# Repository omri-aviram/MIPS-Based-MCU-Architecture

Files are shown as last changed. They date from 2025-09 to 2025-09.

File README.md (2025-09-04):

# MIPS-Based-MCU-Architecture
This project implements a full MCU system on FPGA, based on a  scalar pipelined MIPS processor. The system integrates core  CPU functionality with memory, bus infrastructure, and  memory-mapped peripherals, creating a working  microcontroller-like environment.  The design was written in VHDL

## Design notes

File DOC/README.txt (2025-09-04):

============================================================
README — MCU Project (MIPS-based Microcontroller on FPGA)
============================================================

Authors:
  • Tal Adoni (31987300)
  • Omri Aviram (312192669)

------------------------------------------------------------
1. Project Overview
------------------------------------------------------------
This project implements a full MCU system on FPGA, based on a 
scalar pipelined MIPS processor. The system integrates core 
CPU functionality with memory, bus infrastructure, and 
memory-mapped peripherals, creating a working 
microcontroller-like environment.

The design was written in VHDL, simulated with ModelSim, and 
synthesized for Altera/Intel Cyclone V FPGA (DE10-Standard 
development board). Timing constraints and functional testing 
were applied to ensure correct operation in hardware.

------------------------------------------------------------
2. System Architecture
------------------------------------------------------------
Top-Level: Quartus_Top.vhd
  • Connects CPU, instruction/data memories, and peripherals.
  • Defines generics for bus width, address width, and 
    synthesis/simulation parameters.
  • Instantiates clocking and reset logic.

Main Components:
  • MIPS.vhd — Pipelined MIPS CPU with 5 pipeline stages:
      - IFETCH.vhd
      - IDECODE.vhd
      - EXECUTE.vhd
      - DMEMORY.vhd
      - CONTROL.vhd
      - HazardUnit_and_ForwardingUnit.vhd
  • MCU.vhd — Wraps CPU with peripheral bus and system control.
  • IO_decoder.vhd — Maps I/O addresses to peripherals.
  • Interrupt_controller.vhd — Handles external/internal IRQs.

Memory:
  • ITCM (Instruction Tightly-Coupled Memory)
  • DTCM (Data Tightly-Coupled Memory)
  • Synchronus FIFO.vhd — FIFO buffer used for FIR/IO
  • Counter.vhd — Generic n-bit counter (timing/events)

Peripherals:
  • Basic_Timer.vhd — Generates interrupts and PWM signals.
  • FIR_filter.vhd — Digital FIR accelerator with FIFO 
    interface for streaming data.
  • HexDecoder.vhd — Drives FPGA 7-segment displays.
  • BidirPin.vhd — Bidirectional I/O pin module.

Packages:
  • const_package.vhd — Global constants (word sizes, addresses).
  • aux_package.vhd — Helper functions and types.
  • cond_comilation_package.vhd — Conditional compilation 
    definitions.

------------------------------------------------------------
3. Features
------------------------------------------------------------
  • Scalar pipelined MIPS CPU (5 stages + hazard resolution).
  • Instruction & Data memories with M9K FPGA blocks.
  • Memory-mapped peripherals: Timer, GPIO, FIR, FIFO, etc.
  • Interrupt controller with priority and vectoring support.
  • Bus-based IO decoding for modular expansion.
  • Clock division for peripherals (FIRCLK ~44 kHz).
  • Hex display output for debugging.

------------------------------------------------------------
4. Simulation & Synthesis
------------------------------------------------------------
Simulation:
  • ModelSim testbenches verify pipeline correctness, memory 
    writes, and peripheral functionality.
  • FIFO and FIR modules were tested with waveform inspection.

Synthesis:
  • Quartus Prime with Cyclone V device.
  • Timing analysis performed with .sdc constraints:
      - create_clock for CLK_IN (50 MHz)
      - derive_pll_clocks for generated clocks
      - FIRCLK domain treated as asynchronous (optional)
  • FPGA tested with actual memory write/read and FIR output.

------------------------------------------------------------
5. Known Issues & Debugging Notes
------------------------------------------------------------
  • ModelSim and Quartus may show different memory initialization 
    order (endianness difference in hex files).
  • FIR filter requires consistent FIFO widths (cell_size must 
    match higher-level instantiations).
  • Critical paths in Quartus should be analyzed to maintain Fmax.
  • Ensure FIFOREN/FIFOWEN signals are pulsed properly to avoid 
    latching issues.

------------------------------------------------------------
6. File List
------------------------------------------------------------
  • Quartus_Top.vhd
  • MCU.vhd
  • MIPS.vhd
    ├── IFETCH.vhd
    ├── IDECODE.vhd
    ├── EXECUTE.vhd
    ├── DMEMORY.vhd
    ├── CONTROL.vhd
    └── HazardUnit_and_ForwardingUnit.vhd
  • Synchronus FIFO.vhd
  • Basic_Timer.vhd
  • FIR_filter.vhd
  • Counter.vhd
  • HexDecoder.vhd
  • IO_decoder.vhd
  • Interrupt_controller.vhd
  • BidirPin.vhd
  • const_package.vhd
  • aux_package.vhd
  • cond_comilation_package.vhd

------------------------------------------------------------
7. Usage Instructions
------------------------------------------------------------
1. Open Quartus project and add all VHDL files.
2. Apply SDC constraints for proper timing closure.
3. Compile project for Cyclone V FPGA (DE10-Standard).
4. Program the FPGA with the generated .sof file.
5. Interact with system via memory-mapped IO (keys, switches, 
   UART or testbench).

------------------------------------------------------------
8. License
------------------------------------------------------------
This project was developed as part of an academic course. 
It is intended for educational purposes only.

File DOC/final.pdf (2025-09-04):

# Final Project - REPORT

# ADVANCED CPU ARCHITECTURE AND HARDWARE MIPS Based MCU Architecture

## Tal Adoni – 319087300

## Omri Aviram – 312192669

במעבדה זו הי ה עלינו לממש architecture MCU based MIPS המשתמשת במעבד ה-MIPS שיצרנו במעבדה קודמת ומחברת אותו עם רכיב ים פריפריאליים באו פן הב א:

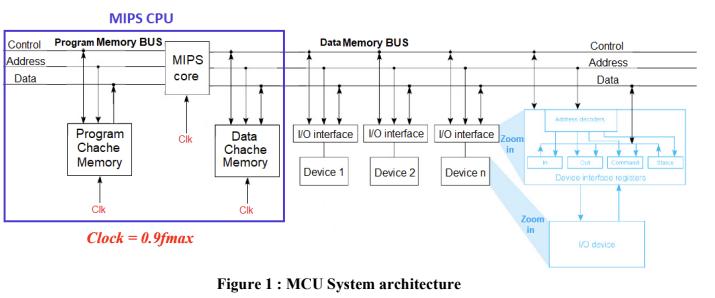
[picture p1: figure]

איור :1 מעבד ה- MCU

כחלק מהפרויקט היה עלינו לבנות ולחבר בין המעבד לבין רכיבים פריפריאליים כאשר דרך התקשורת בינם לבין ה- CPUנעשית על ידי שלושה קווים: Data and Address ,Control וכל אחד מהקווים הללו נכנסו למודולים כך שקווי הבקרה היו כתיבה/קריאה מהזיכרון )שהגיעו מתוך השלב של הזיכרון( כיוון שאופן העבודה במערכת נעשה באמצעות מיפוי רכיבי ה-IO והרגיסטרים שלהם באמצעות הזיכרון לפי התמונה הבאה – כאשר החלק הלבן הוא הזיכרון שלנו והחלק הורוד הוא הזיכרון " הוירטואלי" זיכרון שאינו חלק ממשי בזיכרון אלא הוא מגיע מתוך רגיסטרי הרכיב ואף חלקם משתנים באופן דינאמי כמו למשל רגיסטר המנייה של

### .Basic Timer

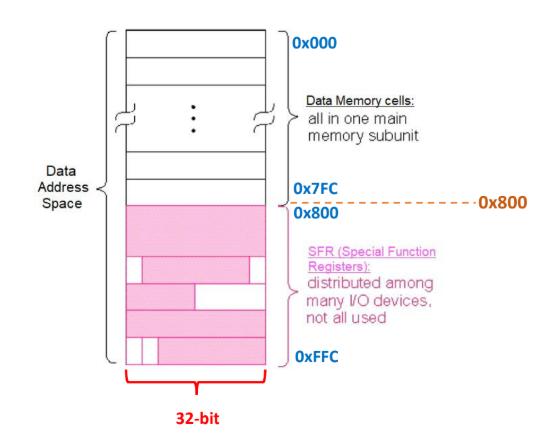
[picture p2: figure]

איור :2 מבנה זיכרון המערכת

### :IO_decoder

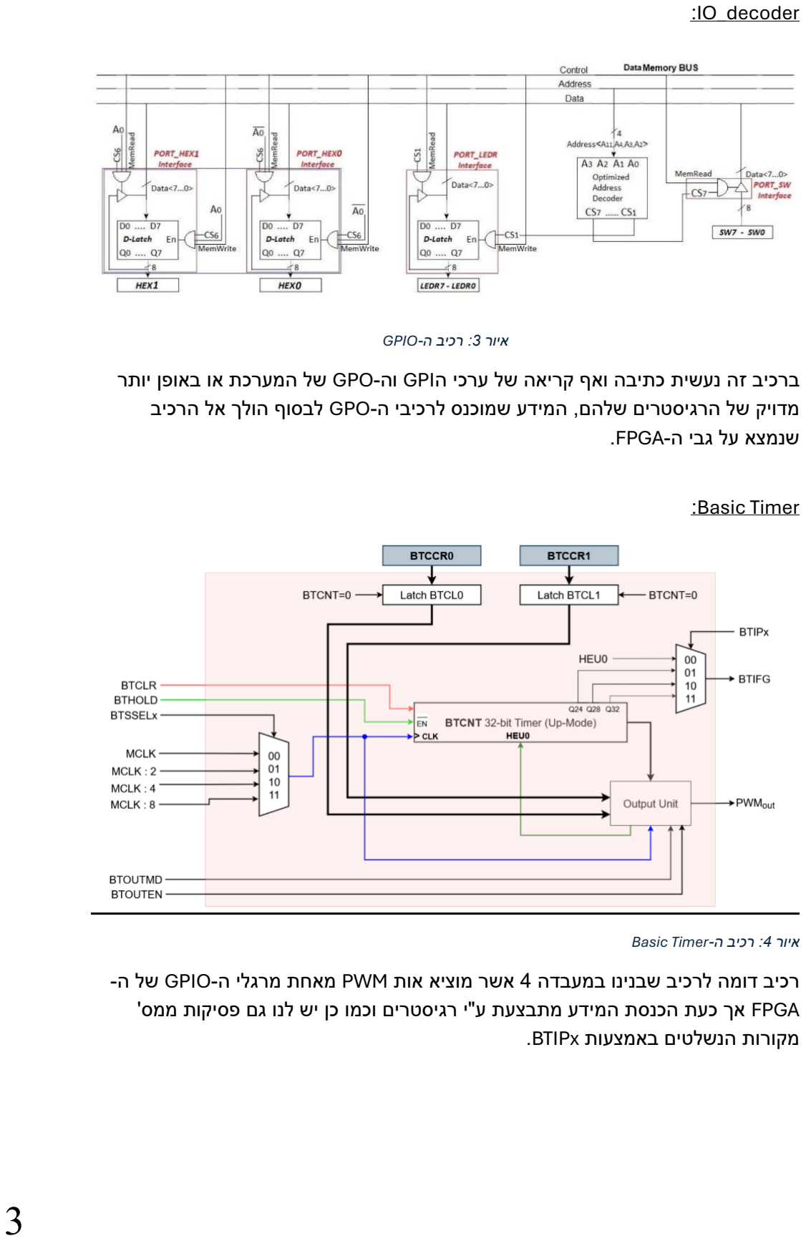
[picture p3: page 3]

איור :3 רכיב ה-GPIO

ברכיב זה נעשית כתיבה ואף קריאה של ערכי הGPI וה-GPO של המערכת או באופן יותר מדויק של הרגיסטרים שלהם, המידע שמוכנס לרכיבי ה-GPO לבסוף הולך אל הרכיב שנמצא על גבי ה-FPGA.

### :Basic Timer

איור :4 רכיב ה-Timer Basic

רכיב דומה לרכיב שבנינו במעבדה 4 אשר מוציא אות PWM מאחת מרגלי ה-GPIO של ה-FPGA אך כעת הכנסת המידע מתבצעת ע"י רגיסטרים וכמו כן יש לנו גם פסיקות ממס' מקורות הנשלטים באמצעות BTIPx.

### :FIR filter

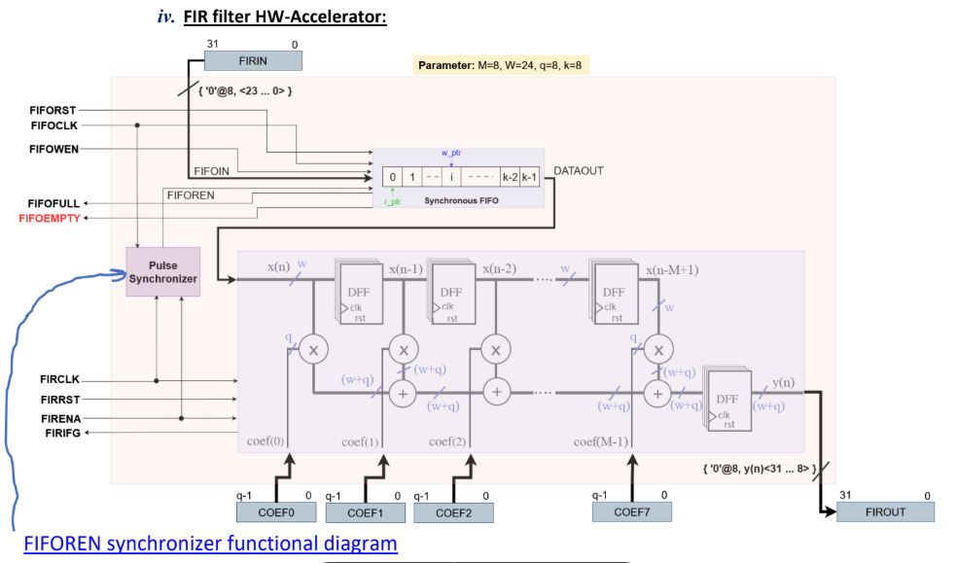
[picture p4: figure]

איור :5 רכיב ה-FIR

פילטר FIR הוא מסנן ספרתי דיסקרטי שעובד בעזרת שני שעונים, איטי ומהיר במקרה שלנו ובו היציאה בכל רגע מחושבת כסכום משוקלל של מספר דגימות קלט אחרונות. היתרון המרכזי שלו הוא יציבות מוחלטת )כי אין משוב פנימי( ושליטה מדויקת בצורת התגובה של התדר.

המודול מקבל רצף דגימות מתוך ה-FIFO synchronous, מכפיל כל דגימה בקבוע משקל )Coefficient), ושולח את התוצאה לסכימה. בצורה זו מתקבלת יציאה שהיא קונבולוציה של האות עם מקדם הפילטר.

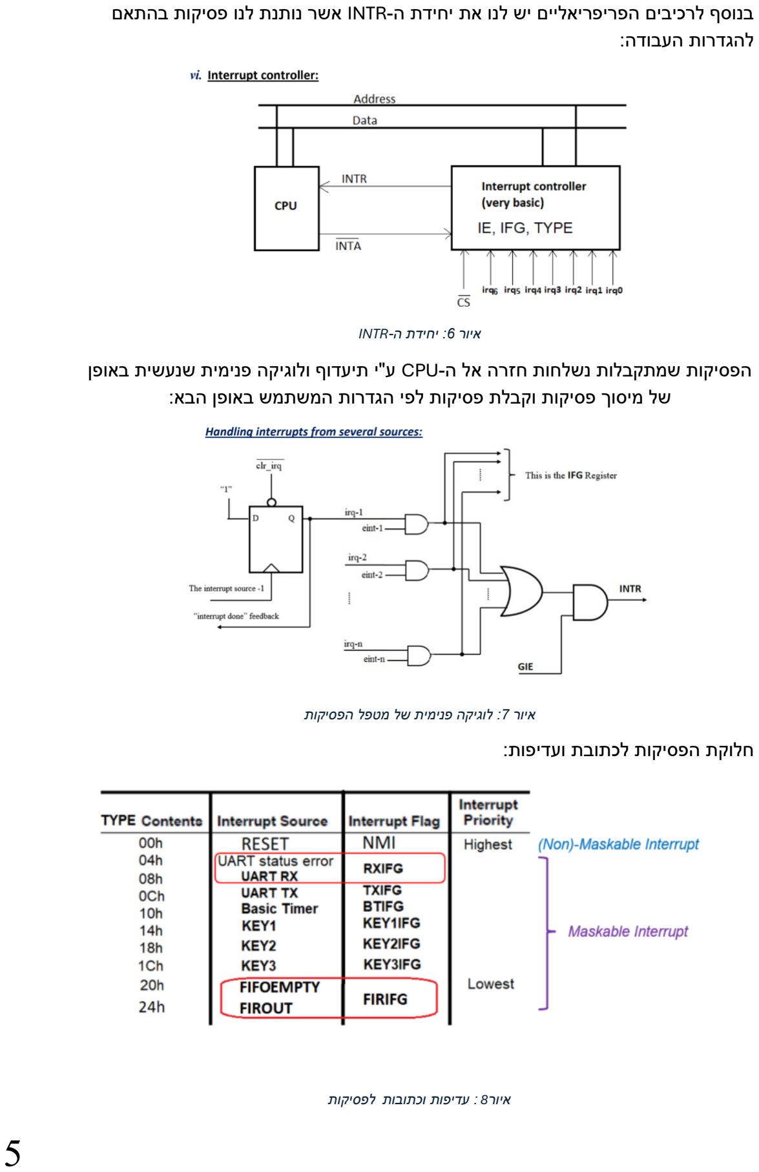
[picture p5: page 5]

בנוסף לרכיבים הפריפריאליים יש לנו את יחידת ה-INTR אשר נותנת לנו פסיקות בהתאם להגדרות העבודה:

איור :6 יחידת ה-INTR

הפסיקות שמתקבלות נשלחות חזרה אל ה-CPU ע"י תיעדוף ולוגיקה פנימית שנעשית באופן של מיסוך פסיקות וקבלת פסיקות לפי הגדרות המשתמש באופן הבא:

איור :7 לוגיקה פנימית של מטפל הפסיקות

חלוקת הפסיקות לכתובת ועדיפות:

איור 8 : עדיפות וכתובות לפסיקות

בעמוד הבא מצורף האיור של המערכת אותה יצרנו.

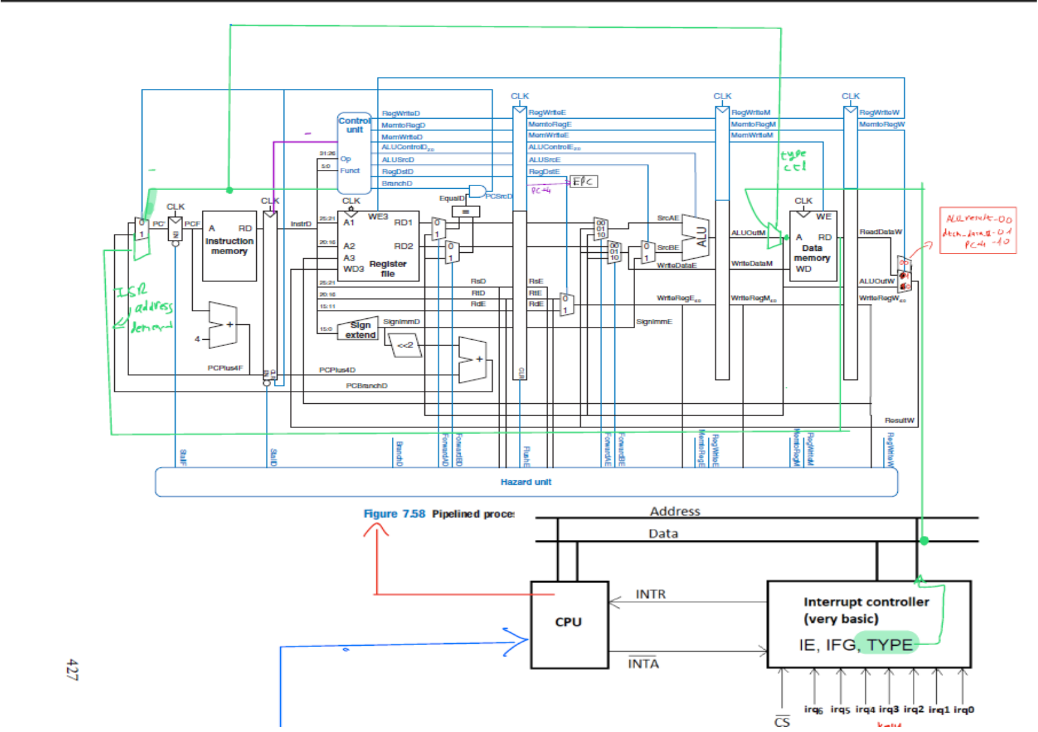
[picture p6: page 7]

7

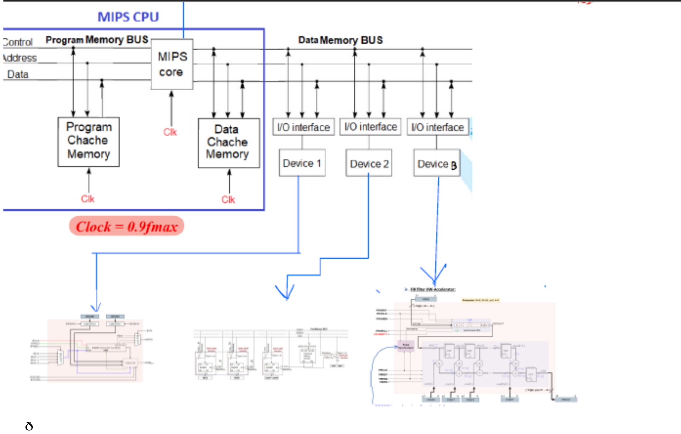
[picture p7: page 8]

8

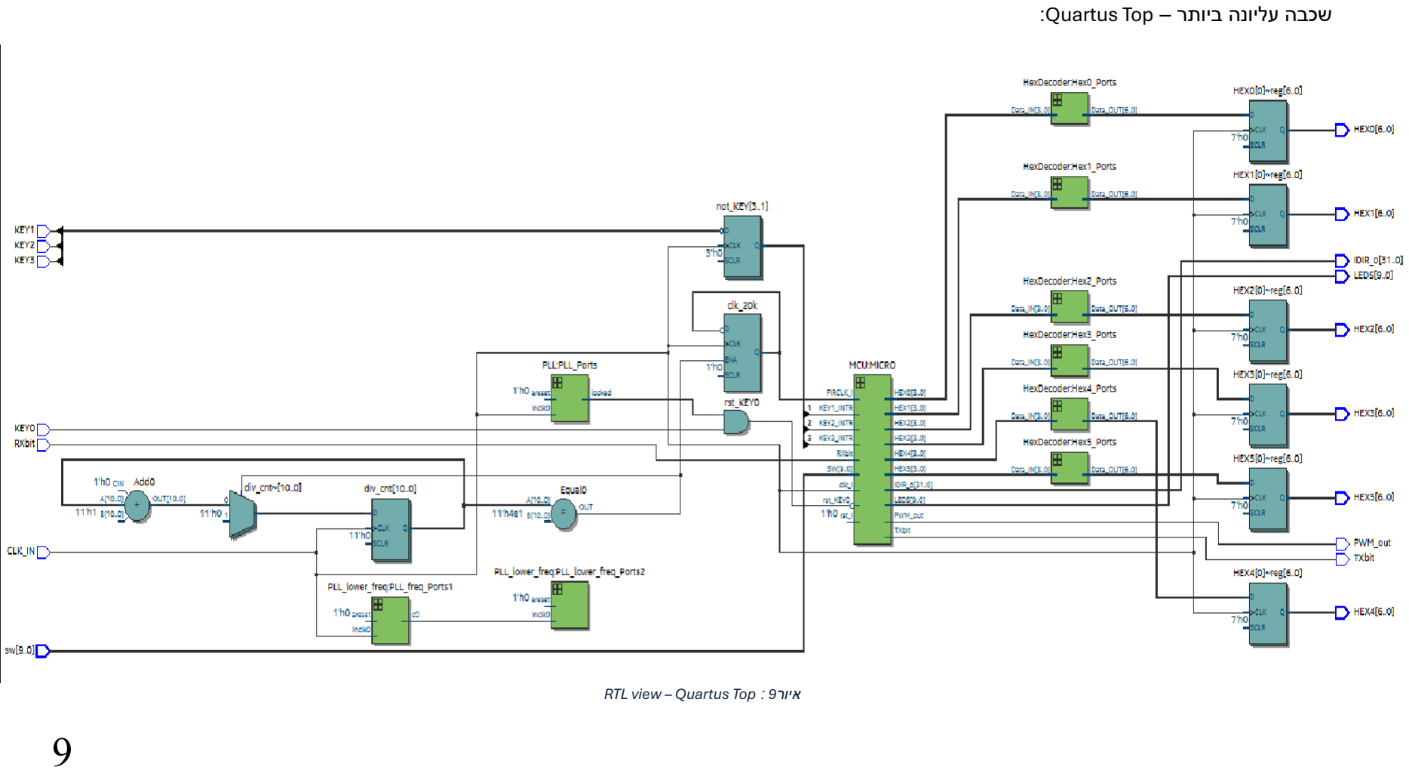
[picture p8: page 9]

9

שכבה עליונה ביותר – Top Quartus:

RTL view – Quartus Top : 9 איור

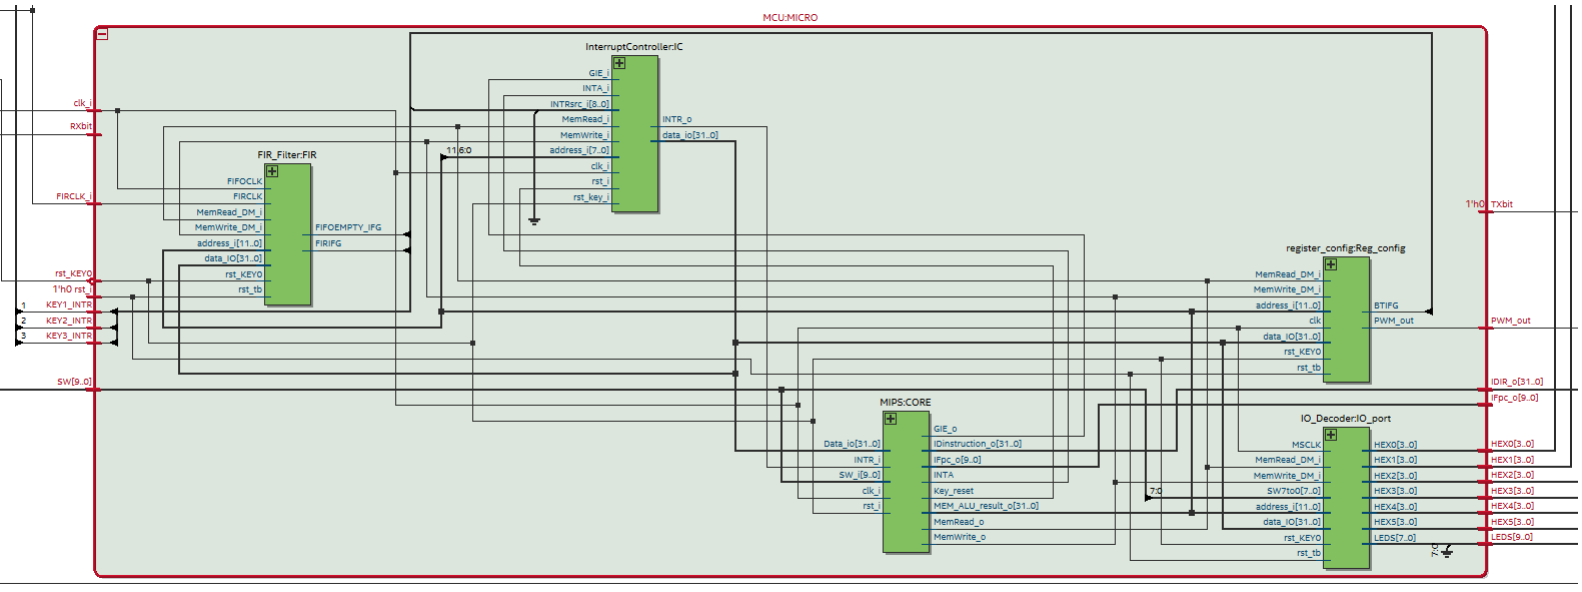
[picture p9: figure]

10

שכבת ה-MCU המכילה את הרכיבים הפריפ ריאליים ואת המעבד:

RTL view - MCU : 10 איור

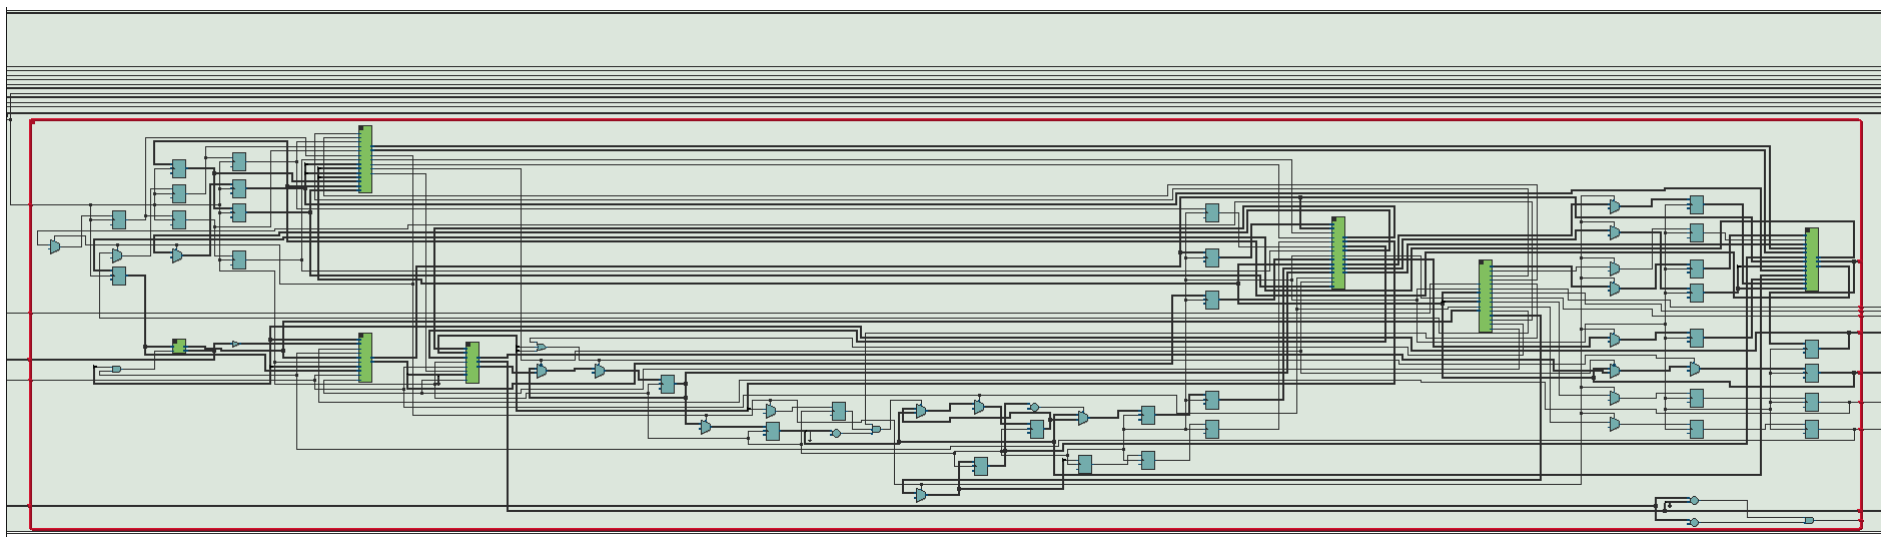
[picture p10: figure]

11

### מעבד המערכת – MIPS Pipelined:

RTL view – Pipeline :11 איור

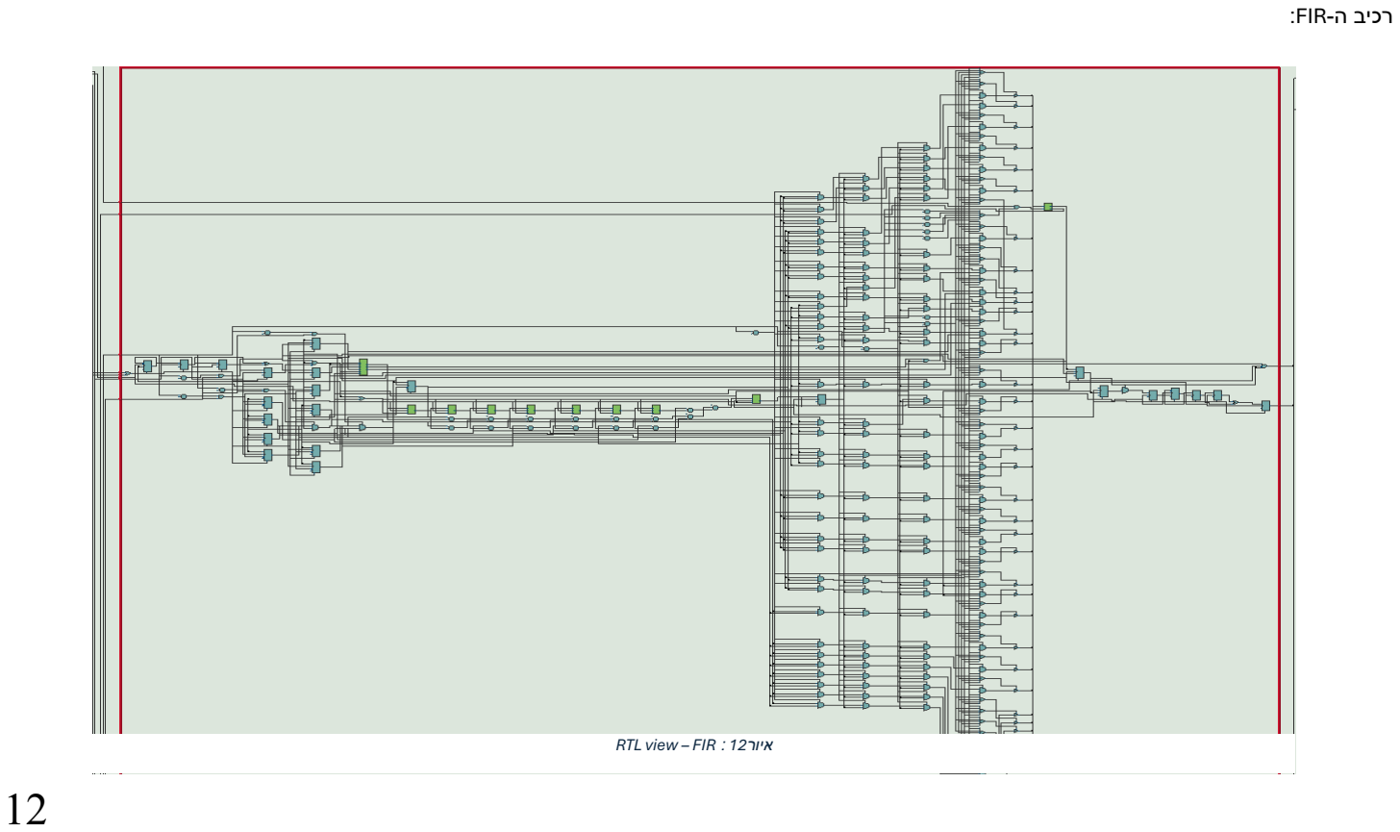
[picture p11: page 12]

12

רכיב ה-FIR:

RTL view – FIR : 12 איור

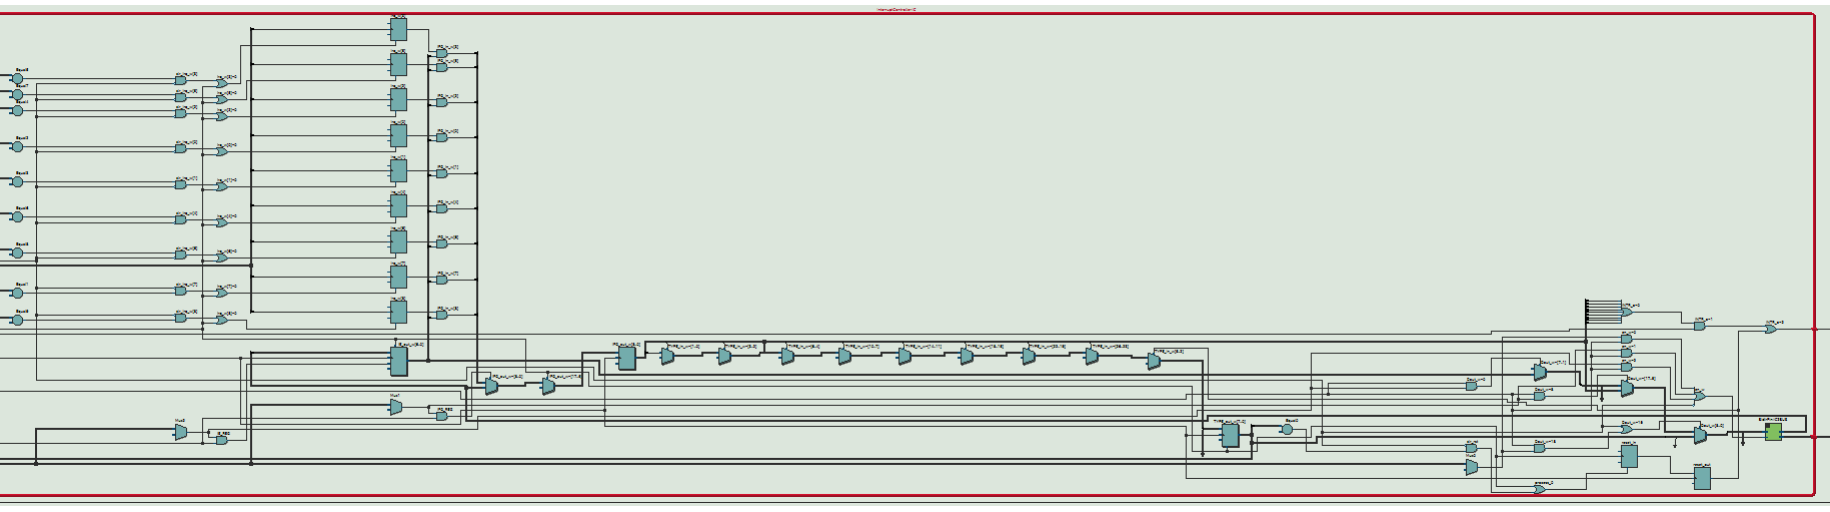
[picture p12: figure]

13

### רכיב ה-Controller Interrupt:

RTL view – FIR : 13 איור

14

### רכיב ה-decode IO:

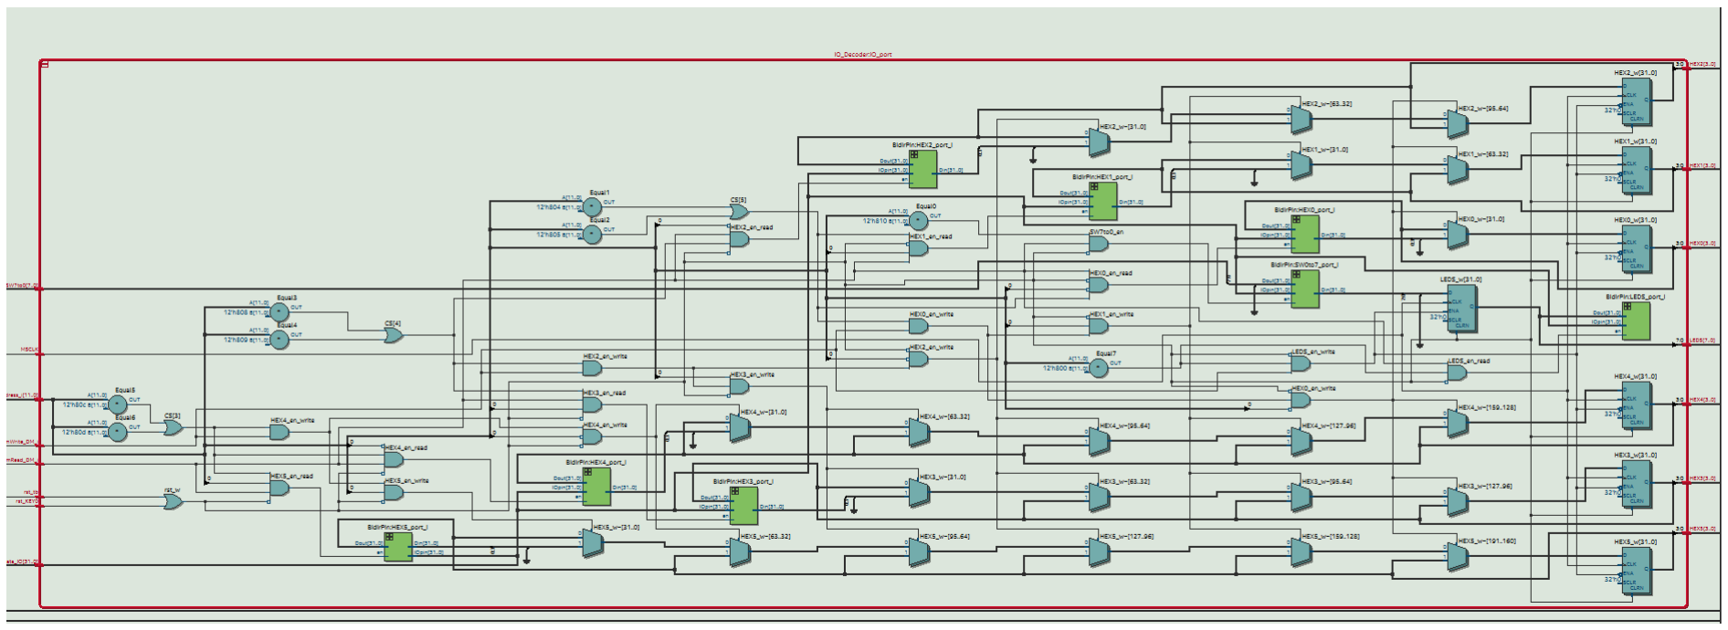
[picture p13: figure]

RTL view – IO decoder :14 איור

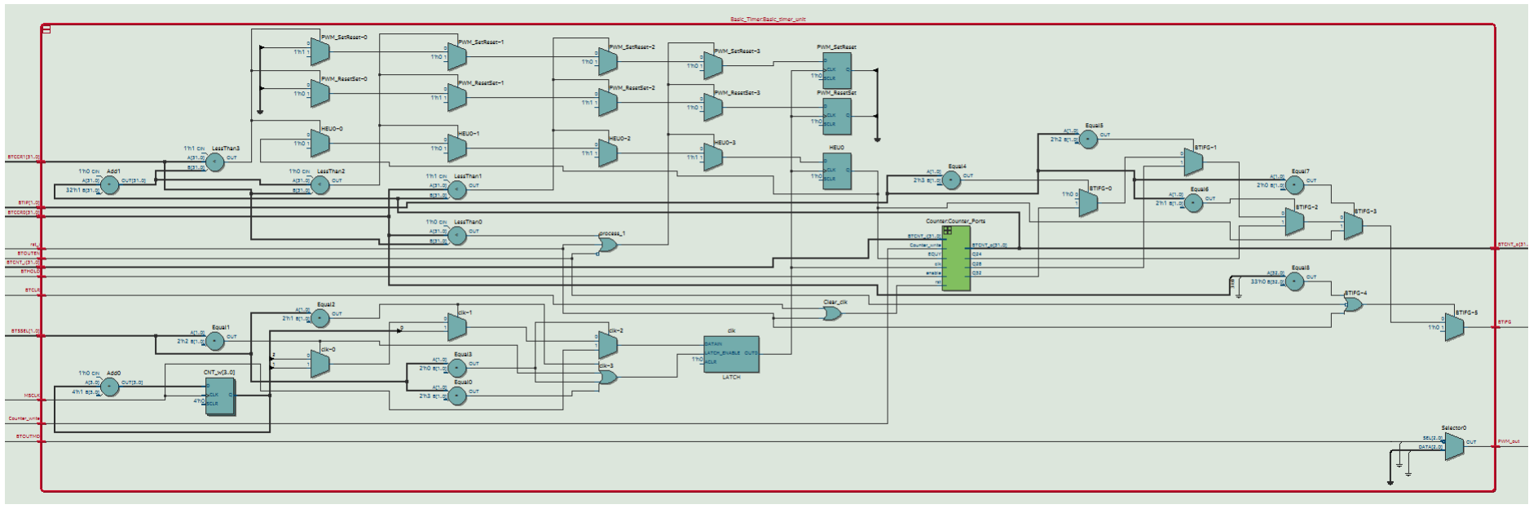
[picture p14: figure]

15

### רכיב ה-Timer Basic:

RTL view – Basic Timer : 15 איור

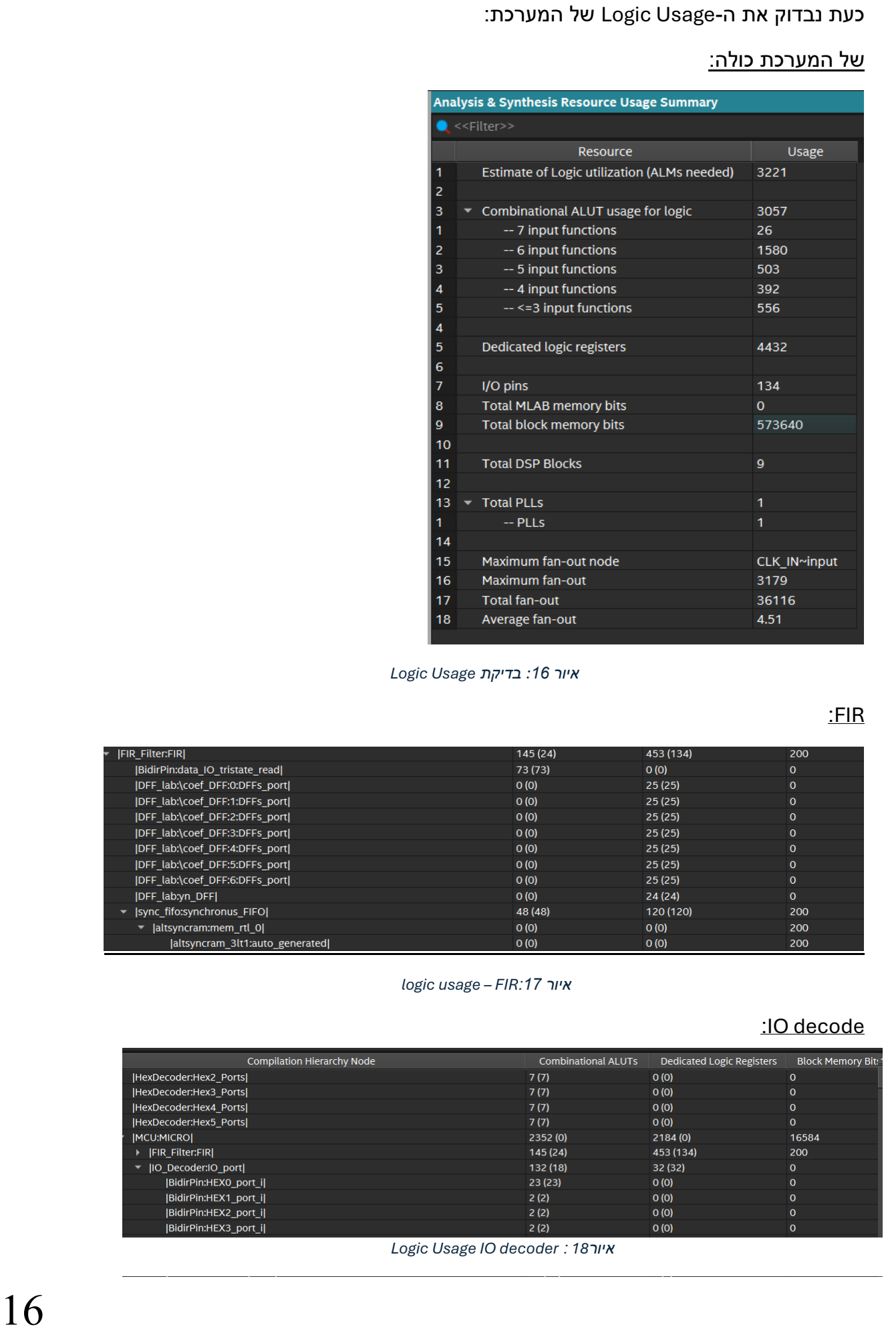
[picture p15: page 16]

כעת נבדוק את ה-Usage Logic של המערכת:

של המערכת כולה:

איור :16 בדיקת Usage Logic

### :FIR

logic usage – FIR:17 איור

### :IO decode

Logic Usage IO decoder : 18 איור

### :Interrupt Controller

Logic usage Interrupt :19 איור

### :MIPS

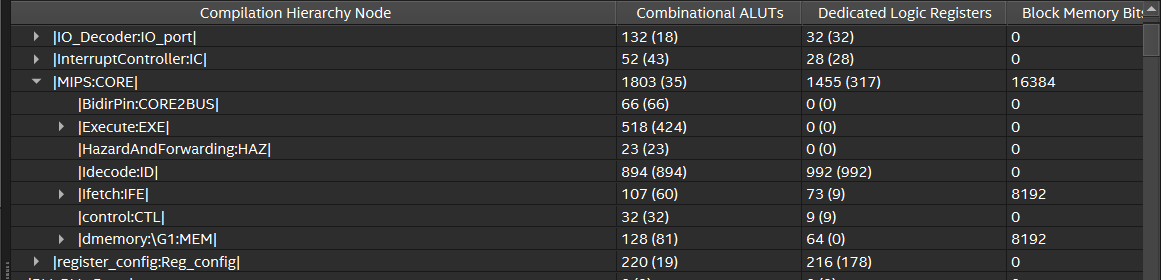
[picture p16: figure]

Logic usage MIPS :20 איור

כעת נבדוק מהו הנתיב הקריטי של המערכת משעון המוצא מה-PLL לעצמו )לצורך מניעה של קבלת ה -PLL כנתיב קריטי(:

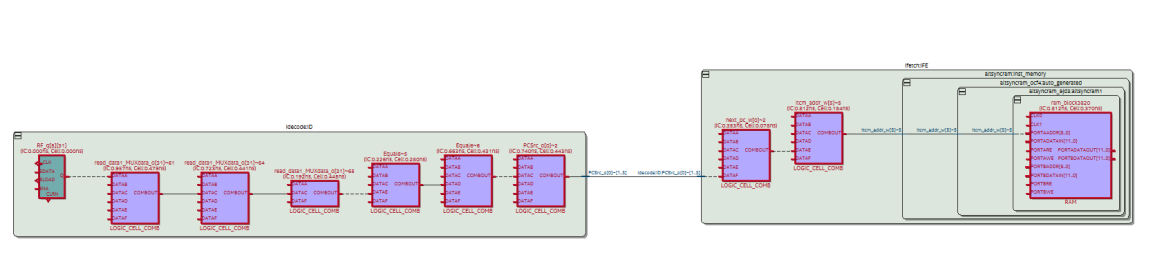
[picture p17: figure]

כצפוי, ובדומה למערכת קודמת קיבלנו שהנתיב הקריטי עובד מה-Fetch ל-Deocode. הדבר מסתדר עם העובדה שהרכיבים האלה אומנם עטופים ברגיסטרים אך החישוב של הכתובות לקפיצה גורם לכך שיש העברת מידע בין שני המודולים.

תדר מקסימלי:

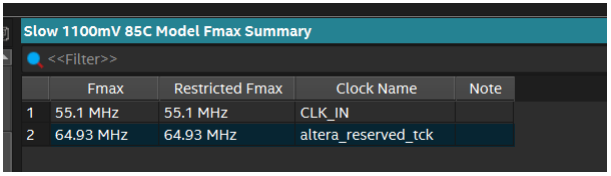
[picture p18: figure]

איור :22 תדר מקסימלי של המערכת

הדבר מסתדר עם תדרי העבודה שלנו כדרוש, כדי לקבל תדר יותר גבוה נוכל לפצל את הנתיב הקריטי שלנו לשני חלקים באמצעות רגיסטר שיפריד בי ן המודולים וכך נ שיג תדר יותר מהיר לכל חלק.

איור 21 : נתיב קריטי של מערכת

### :Code Verification

לצורך וריפיקציה והוכחת עבודה של הקוד נציג ModelSim ו-SignalTap של 2test מתוך קובץ בדיקות עם פסיקה שניתנו לנו בעבודה זו וגם את 2test מ-GPIO.

בבדיקת ה-ModelSim הכנסנו לחיצה על 1KEY לאחר us100 לכן נקפוץ לנקודה זו ונראה כיצד הדבר משפיע:

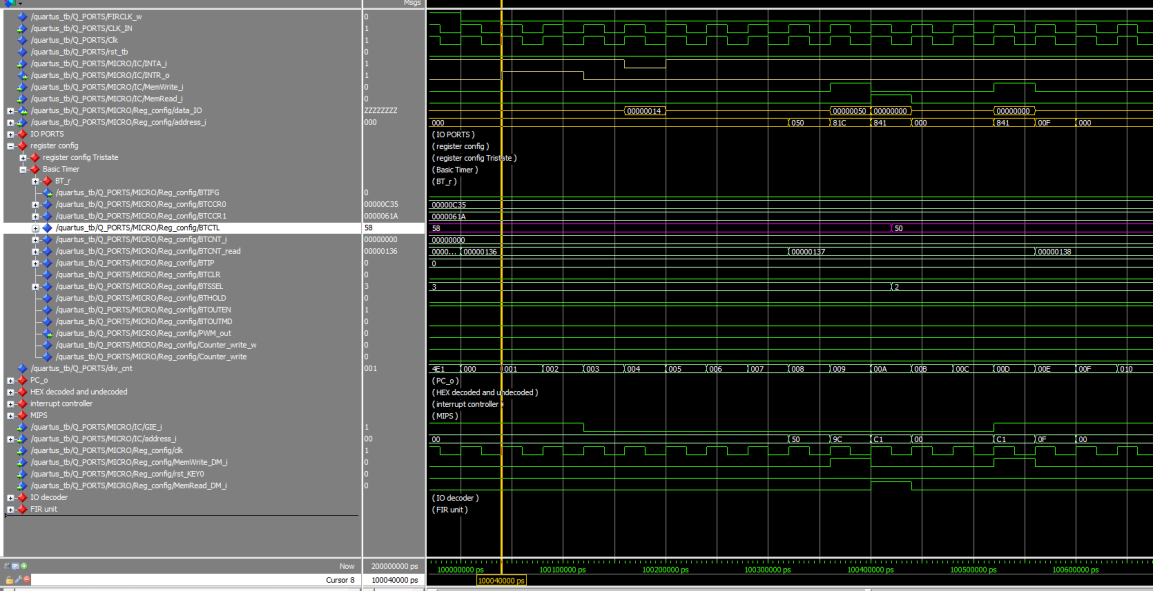
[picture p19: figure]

איור :23 תמונה מ2-test modelsim

ניתן לראות כי אכן מתקבלת בקשת פסיקה עבור כתובת 14x0 ברגע שINTA יורד – כלומר רוטינת השירות שתתקבל תהיה של 1KEY בהתאם למה שרצינו. כמו כן ניתן לראות כי לאחר זמן מה משתנה ערך BTCTL מ50- ל58- כדרוש בטסט.

כעת נרצה להשוות את התוצאות לאלו שיתקבלו ב-SignalTap:

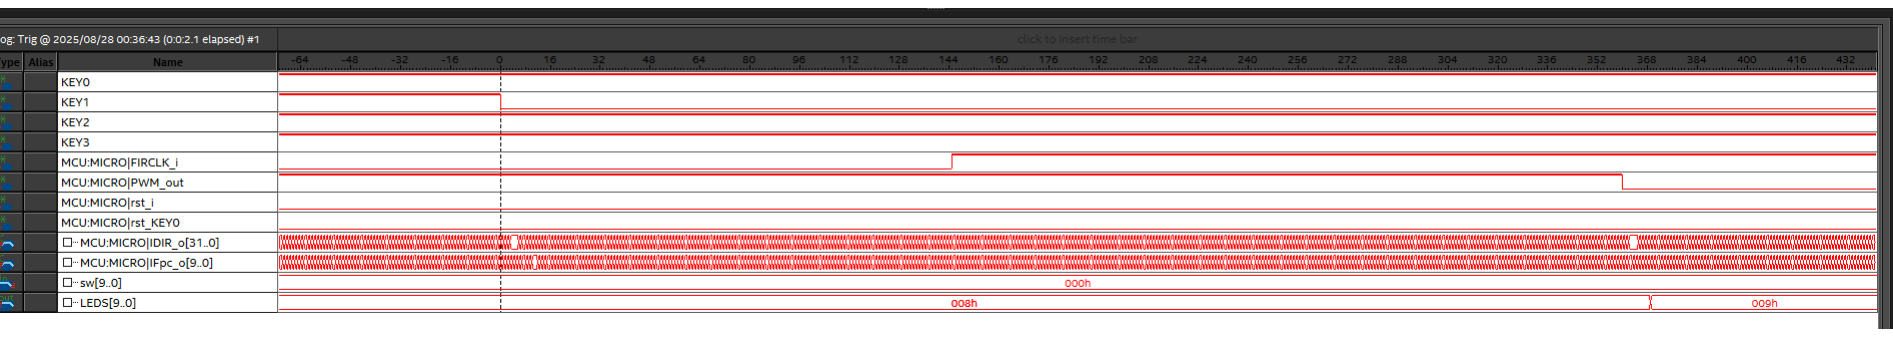
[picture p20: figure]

איור 24 : טסט 2 interruptsמ- SignalTap

בחרנו את 1KEY בתור טריגר ואכן ניתן לראות, באופן דומה ל-ModelSim כצפוי, כי קיבלנו INTR ובעת ירידת INTA אנו מעבירים דרך IO_data את ערך הפסיקה 14 ולאחריו מתחיל הטיפול בפסיקה ואנחנו רואים את הטיפול בפסיקה על ידי שינוי תדר ה-PWM.

תמונה של ה- FPGA:

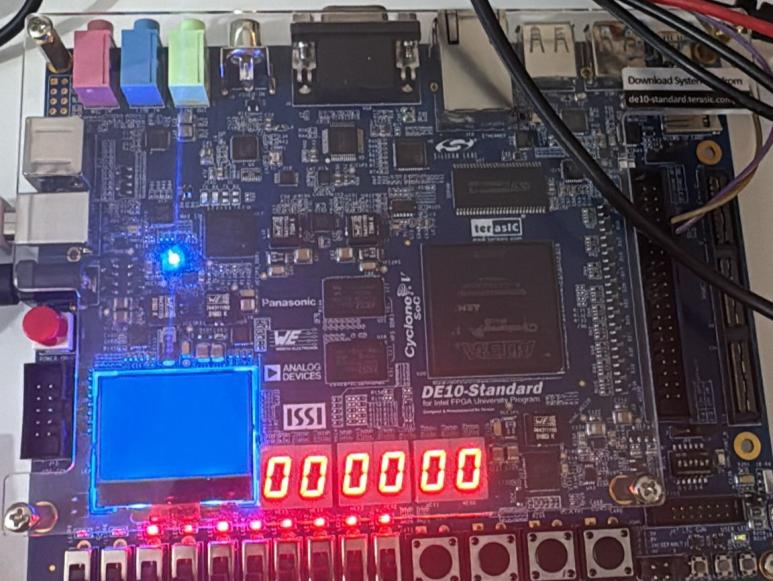
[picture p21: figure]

איור :25 תמונה של Interrupt 2test FPGA

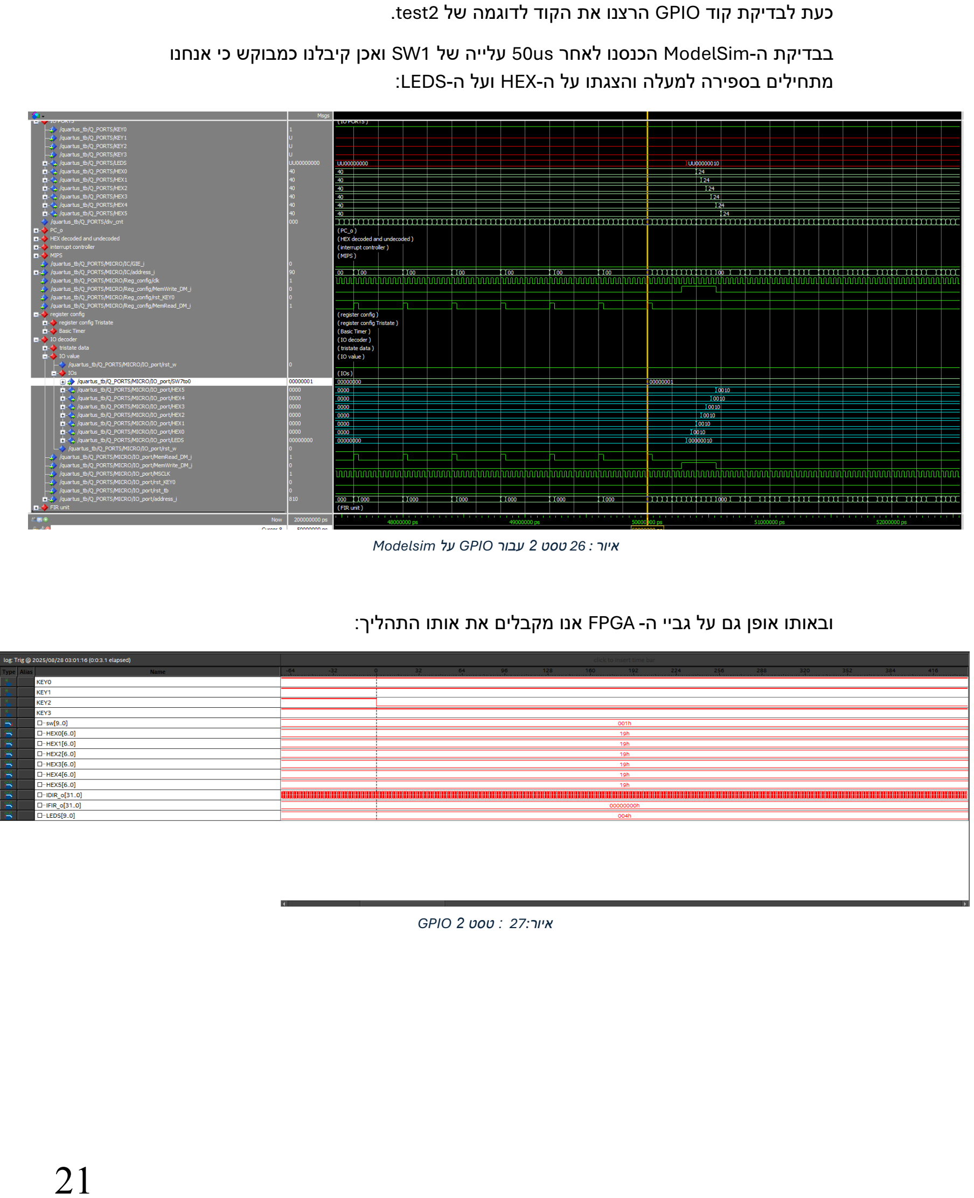
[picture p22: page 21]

כעת לבדיקת קוד GPIO הרצנו את הקוד לדוגמה של 2test.

בבדיקת ה-ModelSim הכנסנו לאחר us50 עלייה של 1SW ואכן קיבלנו כמבוקש כי אנחנו מתחילים בספירה למעלה והצגתו על ה-HEX ועל ה-LEDS:

ובאותו אופן גם על גביי ה- FPGA אנו מקבלים את אותו התהליך:

איור : 26 טסט 2 עבור GPIO על Modelsim

איור 27: : טסט 2 GPIO

תמונה של ה- FPGA:

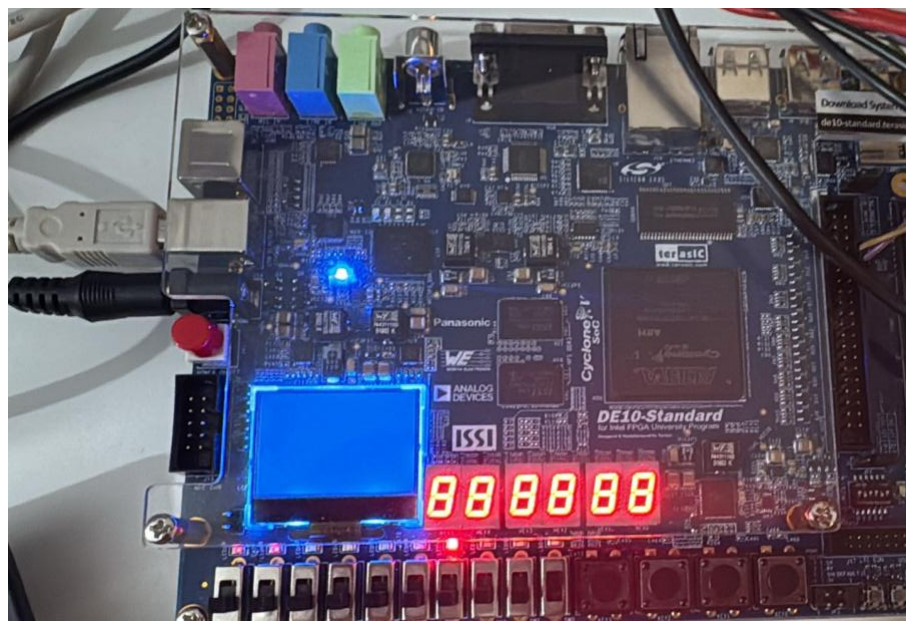
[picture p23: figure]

איור 28 : תמונה של GPIO 2test FPGA

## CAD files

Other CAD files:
QUARTUS/signalTapForFIR.stp
